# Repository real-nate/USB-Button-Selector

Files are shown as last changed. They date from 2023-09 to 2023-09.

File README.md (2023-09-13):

# USB-Button-Selector
Send keystrokes on USB-connected button from selection using rotary encoder. Current ready-to-use setup is for launching Steam games.

The implementation works by using the Adafruit board running as a HID (human interface devices, e.g. keyboard), while taking input from the connected button and rotary encoder. An LCD screen displays the current selection, and the button actives the script.

## Hardware
The Adafruit shopping list can be found here: [https://www.adafruit.com/wishlists/579808](https://www.adafruit.com/wishlists/579808)
* Large Arcade Button with LED-60mm red (PID: 1190, ~$6)
* Rotary Encoder (PID: 377, ~$5)
* USB A/Micro Cable (PID: 2185, ~$5)
* Standard LCD 16x2 display (PID: 181, ~$10)
* Adafruit ItsyBitsy M0 Express (PID: 3727, ~$12)
Total: ~$37 (as of Sept. 2023)

Housing is also highly recommended. 3D models with corresponding FreeCAD files are provided in the `model` directory. The below screws are used to connect the base with the top and the LCD screen to the top.
* M3 (x4)
* M5 (x4)

### Assembly
Please refer to guide in the 'docs' directory.

## Software
The ItsyBitsy M0 Express board is an HID-compatible board that runs CircuitPython. The install is summarized in the `docs` directory, and the full process is explained by Adafruit at [https://learn.adafruit.com/introducing-itsy-bitsy-m0/circuitpython](https://learn.adafruit.com/introducing-itsy-bitsy-m0/circuitpython).

For an as-is setup, simply drag the contents of the `src/all-in-one/` directory to the `CIRCUITPY` drive and wire the connections on the board according to the wiring diagram in the `docs` directory.

### Libraries
The default CircuitPython install comes with all but two of the necessary libraries: `charlcd` and `hid`. The full libraries in their original zip are in `src/lib-full`. However, to save space on the device (and be able to load the code), abbreviated libraries are used and found in `src/lib`.

### Updating Game List
The 'as-is' implementation has five games loaded into an array of names and another array of corresponding Application ID's. To add a game, simply add the name as you want it displayed to the `gameList` array, and add the Application ID to the same index (position) in the `gameNums` array. Application ID's can be found on Steam by right-clicking a game, selecting properties, and navigating to 'Updates'. The App ID is at the bottom of the page.

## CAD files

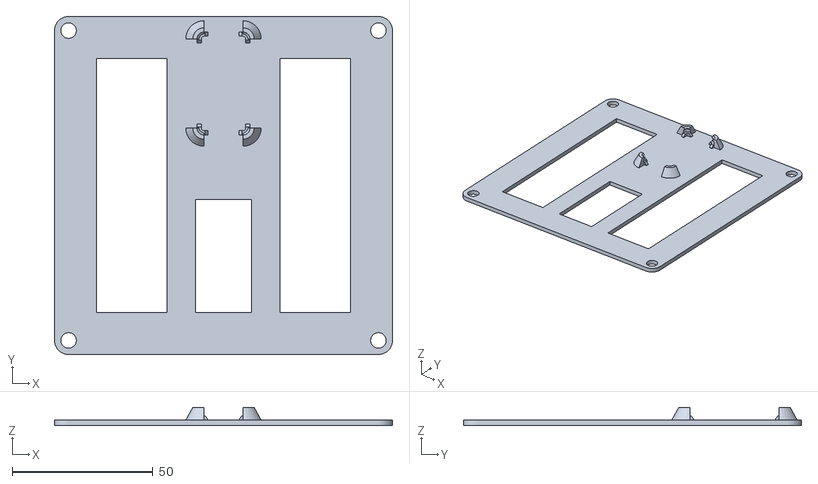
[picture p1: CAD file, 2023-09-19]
model/mechanical/main-main-bottom_v2.stl
120.0 x 120.0 x 6.50

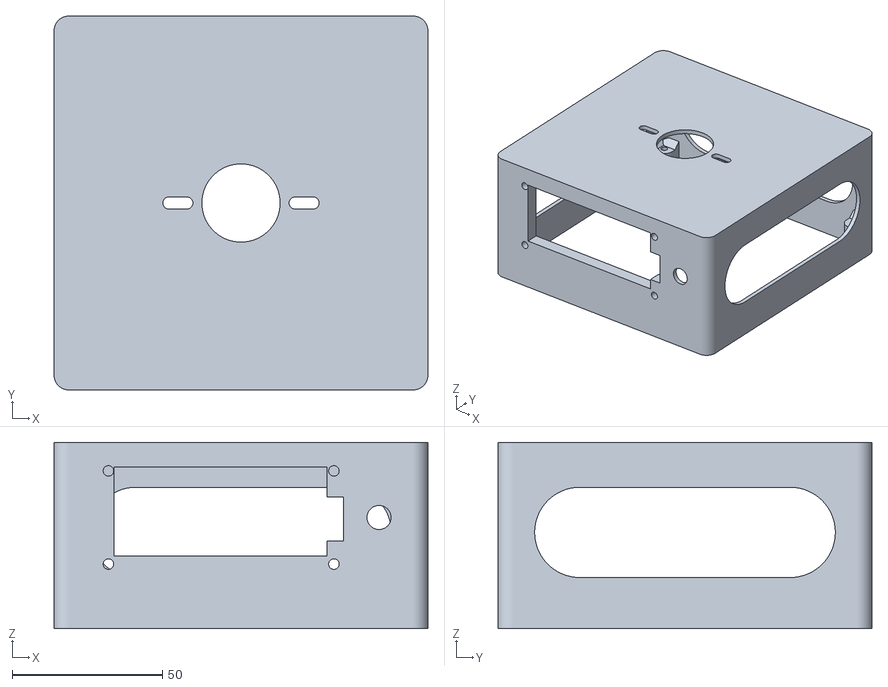
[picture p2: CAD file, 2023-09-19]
model/mechanical/main-main-top_v2.stl
124.4 x 124.4 x 62.0

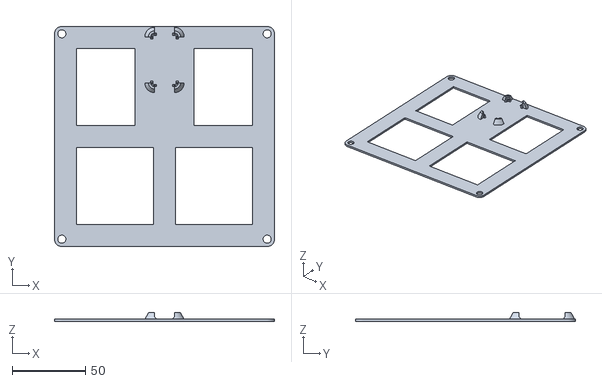
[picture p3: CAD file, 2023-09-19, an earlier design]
model/mechanical/main-main-bottom_v1.stl
150.0 x 150.0 x 6.00

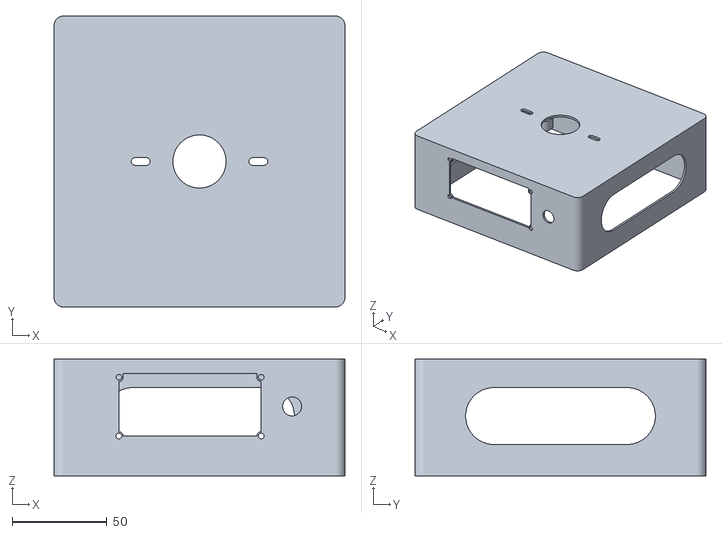
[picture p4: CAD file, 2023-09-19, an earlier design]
model/mechanical/main-main-top_v1.stl
153.4 x 153.4 x 61.5

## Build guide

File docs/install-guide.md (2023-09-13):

# Installation Guide
The following document gives a walk-through of how to build and setup up the software and hardware. Links are also provided for further reference. Many thanks to the Adafruit website and creators, because of which this project is possible.

## Hardware
### Mechanical
The largest piece of this project is the housing, given as a top and bottom part. The bottom part holds the ItsyBitsy M0 Express board and is connected to the top part by four M5 screws. The top part holds the button (no need for modeled threads, button comes with plastic nut), LCD display connected using four M3 screws, and the rotary encoder connected using a washer and nut. Assembling these pieces is straightforward, with a note to be careful about snapping the M0 Express board into place.

### Electrical
The following schematic should be used with the default configuration of the code.
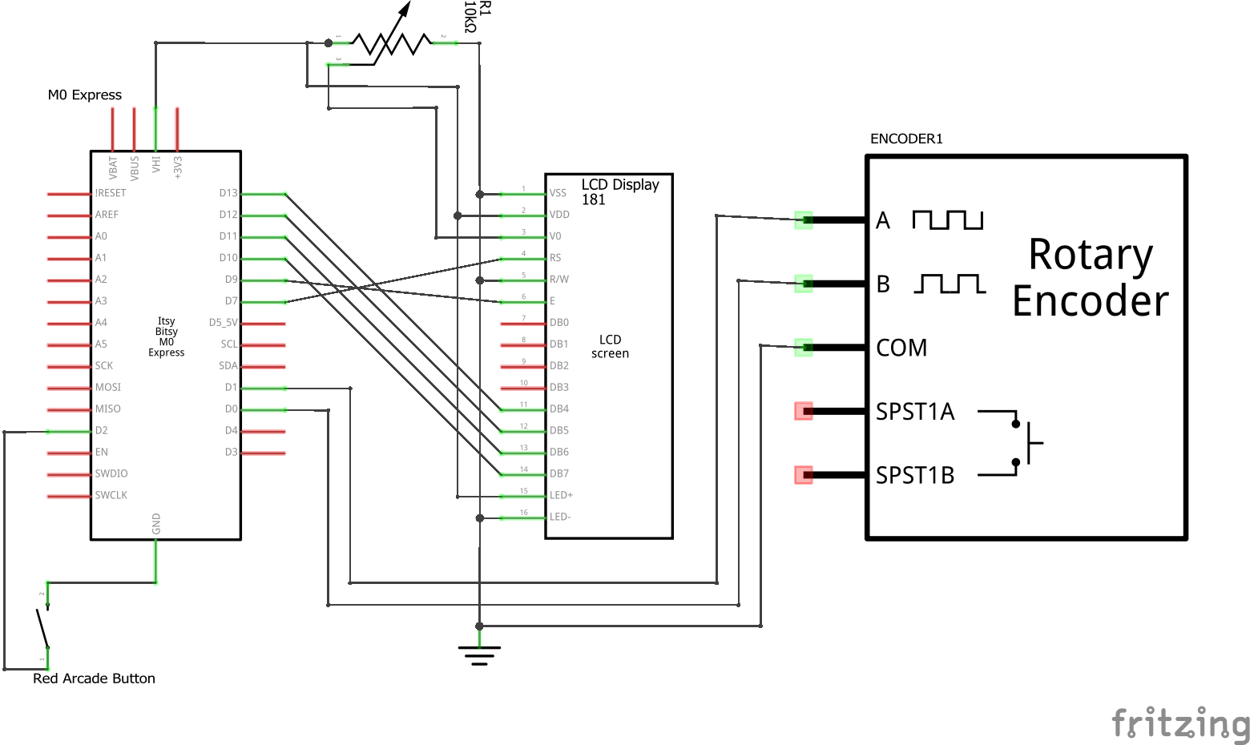
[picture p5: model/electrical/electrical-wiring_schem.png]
Circuit Diagram


A summary of the connections is as follows
#### Arcade Button
* Bottom pin to `GND`
* Side pin to `BOARD-D02`
Reference: [https://learn.adafruit.com/ninja-timer-giant-7-segment-display/wire-the-buttons](https://learn.adafruit.com/ninja-timer-giant-7-segment-display/wire-the-buttons)

#### LCD Display
* `LCD-01` -> `GND`
* `LCD-02` -> `BOARD-VHI`
* `LCD-03` -> `10kTRIM-Wiper`
* `LCD-04` -> `BOARD-D07`
* `LCD-05` -> `GND`
* `LCD-06` -> `BOARD-D09`
* `LCD-07..LCD-10` -> No connection
* `LCD-11` -> `BOARD-D13`
* `LCD-12` -> `BOARD-D12`
* `LCD-13` -> `BOARD-D11`
* `LCD-14` -> `BOARD-D10`
* `LCD-15` -> `BOARD-VHI`
* `LCD-16` -> `GND`
Reference: [https://learn.adafruit.com/character-lcds/wiring-a-character-lcd](https://learn.adafruit.com/character-lcds/wiring-a-character-lcd)

#### 10k Trim Potentiometer
* Outer pins to `BOARD-VHI` and `GND` (arbitrary arrangement)
* Center pin to `LCD-03`

#### Rotary Encoder
* `RE-A` -> `BOARD-D1`
* `RE-B` -> `BOARD-D0`
* `RE-COM` -> `GND` (center pin)
Also connection for button possible (not implemented in the code currently)
Reference: [https://learn.adafruit.com/bluetooth-le-hid-volume-knob-with-circuitpython/build-the-ble-volume-knob](https://learn.adafruit.com/bluetooth-le-hid-volume-knob-with-circuitpython/build-the-ble-volume-knob)

## Software
The best software guide is found at Adafruit for the ItsyBitsy M0 Express: [https://learn.adafruit.com/introducing-itsy-bitsy-m0/overview](https://learn.adafruit.com/introducing-itsy-bitsy-m0/overview). Here, the guide is summarized with some quick troubleshooting. The bootloader and CircuitPython files are also provided in this repository in the `src/board-init/` directory.

### First Time Setup
When the ItsyBitsy M0 Express board is first plugged in to the computer, double-click the reset button on the board to enter the boot volume called `ITSYBOOT`. Drag the `adafruit-circuitpython-itsybitsy_m0_express-en_US-8.2.5.uf2` file (in `src/board-init/`) to the boot volume. The M0 Express should restart and a new volume called `CIRCUITPY` should appear.

The Bootloader may need to be updated. If this is the case, double-click the reset button and drag the `update-bootloader-itsybitsy_m0-v3.15.0.uf2` file to the boot volume instead of the circuit python file. Once the M0 Express restarts, drag the circuit python `uf2` file back onto the boot volume as before.

A more complete overview of CircuitPython install is found at [https://learn.adafruit.com/welcome-to-circuitpython/installing-circuitpython](https://learn.adafruit.com/welcome-to-circuitpython/installing-circuitpython). The latest CircuitPython and Bootloader files can be downloaded from [https://circuitpython.org/board/itsybitsy_m0_express/](https://circuitpython.org/board/itsybitsy_m0_express/).

### Running Code
The simplest setup is to drag the contents of the `src/all-in-one/` directory to the `CIRCUITPY` drive. This adds the required libraries and overwrites the default `code.py` script. Adafruit recommends to edit the python code directly on the `CIRCUITPY` volume using the Mu editor (more information [https://learn.adafruit.com/welcome-to-circuitpython/recommended-editors](https://learn.adafruit.com/welcome-to-circuitpython/recommended-editors)).

### Troubleshooting
If a bootloader for a different board was accidentally loaded instead of the ItsyBitsy M0 Express bootloader, the board's internal storage must be cleared and the new bootloader re-uploaded. If the board's REPL (read, evaluate, print, loop) is accessible, simply run the following two lines of code:
```python
import storage
storage.erase_filesystem()
```
If the issue is not solved, please refer to [https://learn.adafruit.com/introducing-itsy-bitsy-m0/troubleshooting](https://learn.adafruit.com/introducing-itsy-bitsy-m0/troubleshooting).

Occasionally, some scripts may fail to allocate enough memory for the program. Using `mpy` files for libraries and well-optimized code helps reduce memory allocation errors. To check free and allocated memory, the following lines of code can be used:
```python
import gc
gc.mem_free()
gc.mem_alloc()
```

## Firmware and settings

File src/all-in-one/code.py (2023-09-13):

# Nathaniel Furman
# 2023
#
# Code credit:
# SPDX-FileCopyrightText: 2018 Kattni Rembor for Adafruit Industries
# SPDX-License-Identifier: MIT
# SPDX-FileCopyrightText: 2022 Ruiz Bros for Adafruit Industries
# SPDX-License-Identifier: MIT

# TODO: maybe add button connection for rotary encoder that switches the order or scroll speed

import board
import digitalio
import rotaryio
import time
import usb_hid
import adafruit_character_lcd.character_lcd as characterlcd
from adafruit_hid.keycode  import Keycode
from adafruit_hid.keyboard import Keyboard

lcd_columns = 16
lcd_rows    = 2

# Game ID's
gameList = ('Valheim', 'Smite', 'Satisfactory', 'Deep Rock Galactic', 'Timberborn')
gameNums = (892970, 386360, 526870, 548430, 1062090)
numGames = len(gameList)

# Initialize button
button = digitalio.DigitalInOut(board.D2)
button.direction = digitalio.Direction.INPUT
button.pull      = digitalio.Pull.UP

# Initialize rotary encoder and keyboard
encoder  = rotaryio.IncrementalEncoder(board.D0, board.D1)
keyboard = Keyboard(usb_hid.devices)

# Initialise the lcd class
lcd = characterlcd.Character_LCD_Mono(
        digitalio.DigitalInOut(board.D7),
        digitalio.DigitalInOut(board.D9),
        digitalio.DigitalInOut(board.D10),
        digitalio.DigitalInOut(board.D11),
        digitalio.DigitalInOut(board.D12),
        digitalio.DigitalInOut(board.D13),
        lcd_columns, lcd_rows,
        digitalio.DigitalInOut(board.D5))

# Function to send keyboard strokes to start game
def runGame(index):
    # [WIN+R], 'cmd', 'start steam://rungameid/{ID}/&exit'
    keyboard.send(Keycode.GUI, Keycode.R)
    time.sleep(0.05)
    keyboard.send(Keycode.C)
    keyboard.send(Keycode.M)
    keyboard.send(Keycode.D)
    time.sleep(0.01)
    keyboard.send(Keycode.ENTER)

    time.sleep(0.05)
    keyboard.send(Keycode.S)
    keyboard.send(Keycode.T)
    keyboard.send(Keycode.A)
    keyboard.send(Keycode.R)
    keyboard.send(Keycode.T)
    keyboard.send(Keycode.SPACE)
    keyboard.send(Keycode.S)
    keyboard.send(Keycode.T)
    keyboard.send(Keycode.E)
    keyboard.send(Keycode.A)
    keyboard.send(Keycode.M)
    keyboard.send(Keycode.SHIFT, Keycode.SEMICOLON)
    keyboard.send(Keycode.FORWARD_SLASH)
    keyboard.send(Keycode.FORWARD_SLASH)
    keyboard.send(Keycode.R)
    keyboard.send(Keycode.U)
    keyboard.send(Keycode.N)
    keyboard.send(Keycode.G)
    keyboard.send(Keycode.A)
    keyboard.send(Keycode.M)
    keyboard.send(Keycode.E)
    keyboard.send(Keycode.I)
    keyboard.send(Keycode.D)
    keyboard.send(Keycode.FORWARD_SLASH)
    for digit in map(int, str(gameNums[index])):
        print(digit)
        print(type(digit))
        if digit == 0:
            keyboard.send(digit + 39)
        else:
            keyboard.send(digit + 29)
    keyboard.send(Keycode.SHIFT, Keycode.SEVEN)
    keyboard.send(Keycode.SHIFT, Keycode.SEVEN)
    keyboard.send(Keycode.E)
    keyboard.send(Keycode.X)
    keyboard.send(Keycode.I)
    keyboard.send(Keycode.T)
    time.sleep(0.01)
    keyboard.send(Keycode.ENTER)


# Set up starting states
button_state = None
last_position = encoder.position
lcd.clear()
lcd.backlight = True

# Main loop
gameCounter = 0
# Display first game in list
lcd.message = '>> ' + gameList[gameCounter][0:lcd_columns-3] + '\n' + gameList[gameCounter + 1][0:lcd_columns]
while True:
    # Read status of the encoder
    current_position = encoder.position
    position_change = current_position - last_position
    if position_change > 0:
        if gameCounter == numGames-1:
        # Loop back to the start
            gameCounter = 0
        else:
            gameCounter += 1
        print(f'Game Counter: {gameCounter}; {gameList[gameCounter]}')
    elif position_change < 0:
        if gameCounter == 0:
        # Loop back to the end
            gameCounter = numGames-1
        else:
            gameCounter -= 1
        print(f'Game Counter: {gameCounter}; {gameList[gameCounter]}')
    last_position = current_position
    print(f'Curr pos: {current_position}')

    # Display current and next game on screen
    if gameCounter == numGames-1:
        lcd.message = '>> ' + gameList[gameCounter][0:lcd_columns-3] + '\n' + gameList[0][0:lcd_columns]
    else:
        lcd.message = '>> ' + gameList[gameCounter][0:lcd_columns-3] + '\n' + gameList[gameCounter+1][0:lcd_columns]
    print(lcd.message)

    # Read status of the button
    if not button.value and button_state is None:
        button_state = "pressed"
    if button.value and button_state == "pressed":
        print("Button pressed.")
        runGame(gameCounter)
        button_state = None
    time.sleep(0.01)

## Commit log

2023-09-13 Pre-construction upload
    All basic code and documentation (except for CAD) before making the device.
    [electrical-wiring.fzz]
2023-09-13 Fixed electric wiring link
2023-09-19 STL Model upload
    [main-main-bottom_v1.stl, main-main-bottom_v2.stl, main-main-top_v1.stl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]
